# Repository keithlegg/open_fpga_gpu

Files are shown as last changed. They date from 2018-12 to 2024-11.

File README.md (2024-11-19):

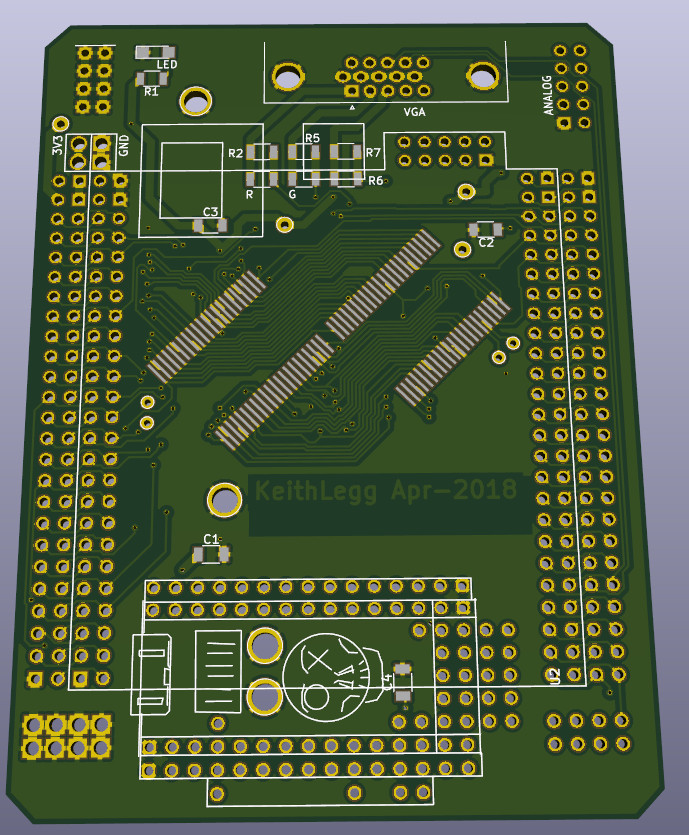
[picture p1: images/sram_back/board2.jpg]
 

# open_fpga_gpu

HERE THERE BE DRAGONS.

This is an experiment. This is probably never going to be much more than that. 

It currently works as an SRAM framebuffer, it can draw the contents of memory to VGA and only draws a single line on the screen.

There will be much done to it before it is even close to ready to be called a "GPU".

HARDWARE:

Features 2 IS62WV51216BLL SRAM chips.

Each SRAM chip has 512K x 16 CMOS low power static RAM

Both chips share the address and data bus with separate programable control lines.

Also has a slot for a 1bitsy ARM chip, not wired directly to the FPGA but there are headers if you want to.

Every mojo pin has been broken out so you can snoop with logic tools, or reconfigure how you want. 
This makes the board much larger, but keeps things easier for prototyping. 

The verilog is added to the mojo-base-project found here:

    https://github.com/embmicro/mojo-base-project

Just copy the files into the src folder, and add the link in ISE GUI before you build the project.

Bresenham code borrowed from here:

    https://github.com/kavinr/Bresenham-Line-Drawing-Algorithm

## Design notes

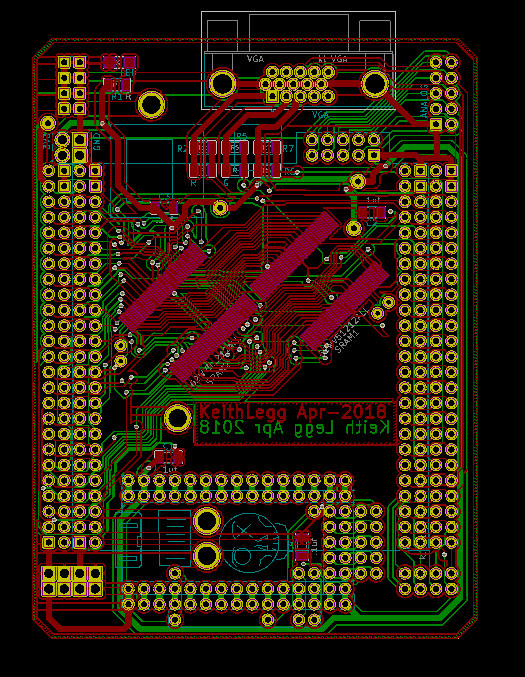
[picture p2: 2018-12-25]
images/sram_back/board1.jpg

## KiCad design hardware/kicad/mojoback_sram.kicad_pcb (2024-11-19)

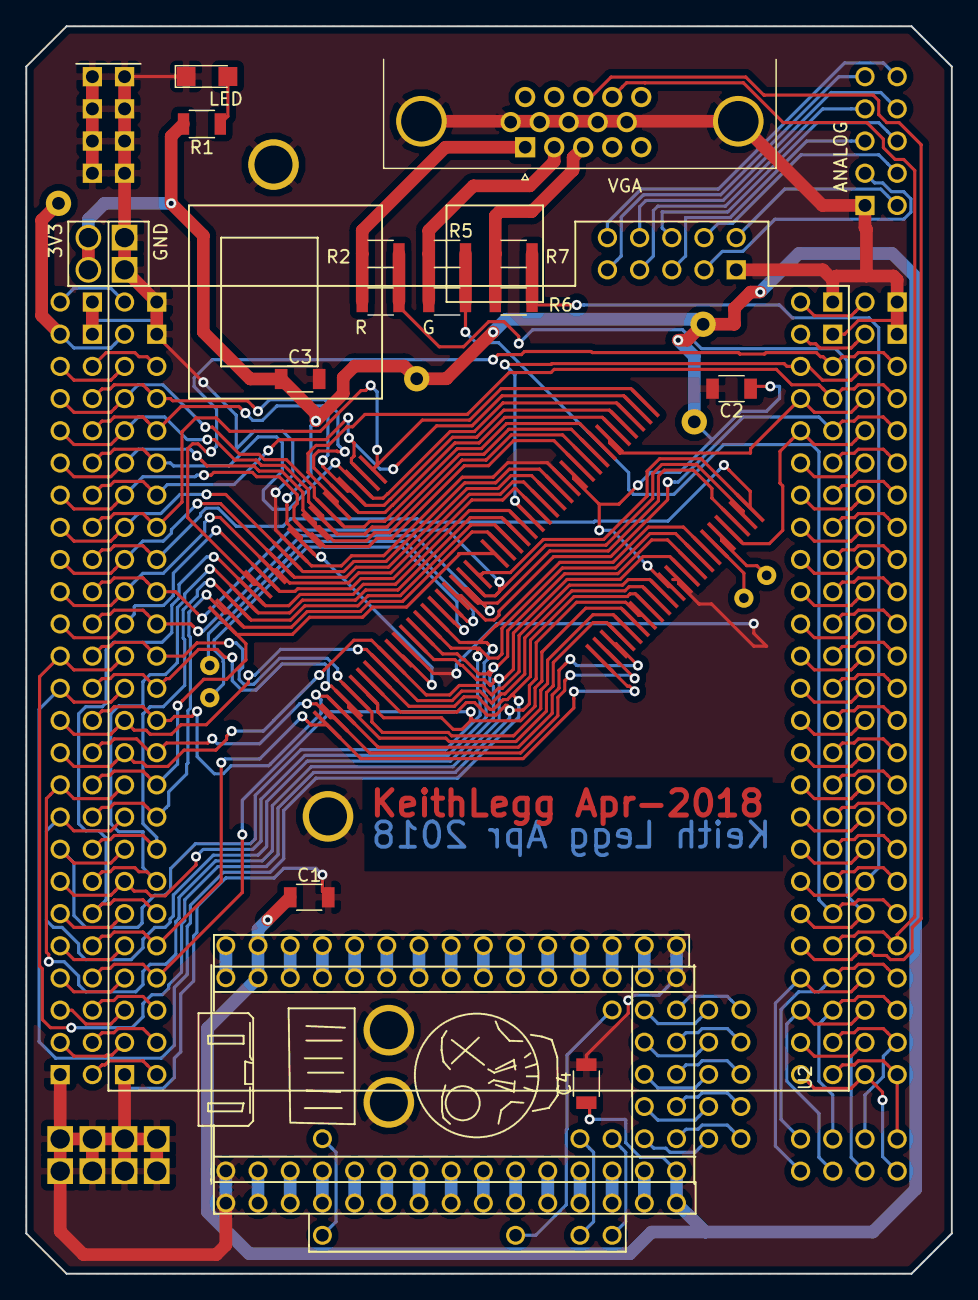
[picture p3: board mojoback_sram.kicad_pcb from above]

Board: 2 copper layers, 73.0 x 98.4 mm, 16 parts (0 on the bottom side), 44 nets.

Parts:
C1, C2, C3, C4: .1uf; C_1206
G: G; R_1206
LED: LED; LED_1206
R, R1: R; R_1206
R2, R5, R7: R_1206
R6: B; R_1206
SRAM1, SRAM2: 62WV51212ALL; KL_TSOP44_Pitch0.8mm
U2: kl_bitsy
VGA: kl_VGA; KL_VGA

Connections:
/3V3: C1.1, C2.1, C3.1, C4.1, R1.2, SRAM1.11, SRAM1.33, SRAM2.11, SRAM2.33, U2.18, U2.42
/A0: SRAM1.5, SRAM2.5
/A1: SRAM1.4, SRAM2.4
/A2: SRAM1.3, SRAM2.3
/A3: SRAM1.2, SRAM2.2
/A4: SRAM1.1, SRAM2.1
/A5: SRAM1.44, SRAM2.44
/A6: SRAM1.43, SRAM2.43
/A7: SRAM1.42, SRAM2.42
/A8: SRAM1.27, SRAM2.27
/A9: SRAM1.26, SRAM2.26
/A10: SRAM1.25, SRAM2.25
/A11: SRAM1.24, SRAM2.24
/A12: SRAM1.22, SRAM2.22
/A13: SRAM1.21, SRAM2.21
/A14: SRAM1.20, SRAM2.20
/A15: SRAM1.19, SRAM2.19
/A16: SRAM1.18, SRAM2.18
/A17: SRAM1.23, SRAM2.23
/A18: SRAM1.28, SRAM2.28
/IO_0: SRAM1.7, SRAM2.7
/IO_1: SRAM1.8, SRAM2.8
/IO_2: SRAM1.9, SRAM2.9
/IO_3: SRAM1.10, SRAM2.10
/IO_4: SRAM1.13, SRAM2.13
/IO_5: SRAM1.14, SRAM2.14
/IO_6: SRAM1.15, SRAM2.15
/IO_7: SRAM1.16, SRAM2.16
/IO_8: SRAM1.29, SRAM2.29
/IO_9: SRAM1.30, SRAM2.30
/IO_10: SRAM1.31, SRAM2.31
/IO_11: SRAM1.32, SRAM2.32
/IO_12: SRAM1.35, SRAM2.35
/IO_13: SRAM1.36, SRAM2.36
/IO_14: SRAM1.37, SRAM2.37
/IO_15: SRAM1.38, SRAM2.38
/b_video: R6.2, R7.2
/clr_b: R6.1, R7.1, VGA.3
/clr_g: G.1, R5.1, VGA.2
/clr_r: R.1, R2.1, VGA.1
/g_video: G.2, R5.2
/r_video: R.2, R2.2
GND: C1.2, C2.2, C3.2, C4.2, LED.1, SRAM1.12, SRAM1.34, SRAM2.12, SRAM2.34, U2.1, U2.29, VGA.0
unnamed: LED.2, R1.1

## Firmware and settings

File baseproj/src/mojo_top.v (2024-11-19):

module mojo_top(
    // 50MHz clock input
    input clk,
    // Input from reset button (active low)
    input rst_n,
    // cclk input from AVR, high when AVR is ready
    input cclk,
    // Outputs to the 8 onboard LEDs
    output[7:0]led,
    // AVR SPI connections
    output spi_miso,
    input spi_ss,
    input spi_mosi,
    input spi_sck,
    // AVR ADC channel select
    output [3:0] spi_channel,
    // Serial connections
    input avr_tx,      // AVR Tx => FPGA Rx
    output avr_rx,     // AVR Rx => FPGA Tx
    input avr_rx_busy, ////

    /********/
    //SPI1 - keith was here, went for beer 
    input klspi_cs,
    input klspi_clk, 
    input klspi_mosi, 
    output klspi_miso,
    /********/
    //SPI2 - echo SPI for logic analyzer snooping - all outputs  
    output klspi_cs_2,
    output klspi_clk_2,
    output klspi_miso2,
    output klspi_mosi2,

    /********/  
    //SRAM data and address buses 

    inout[15:0]sram_bidir, 
    output[18:0]sram_a,

    /********/ 
    //sram1 control bus 
    output sram1_we,//active low
    output sram1_cs,//active low
    output sram1_oe,//active low

    //sram2 control bus 
    output sram2_we,//active low
    output sram2_cs,//active low
    output sram2_oe,//active low

    /********/    
    //VGA output        
    output rpin,
    output gpin,
    output bpin,
    output vpin,
    output hpin

    );


/********************************/

wire inv_rst;         
assign inv_rst = ~rst_n;

/********************************/
//initialize values - "plugz"

// these signals should be high-z when not used
assign spi_miso = 1'bz;
assign avr_rx = 1'bz;
assign spi_channel = 4'bzzzz;


//echo SPI to second bus 
assign klspi_cs_2 = klspi_cs;
assign klspi_clk_2 = klspi_clk; 
assign klspi_mosi2 = klspi_mosi; 
assign klspi_miso = 1'b1;
assign klspi_miso2 = 1'b1;

/******************************************/
// SRAM interface  - chip1 is on right of board when VGA is top 
/******************************************/

wire we_wire1; // high on read, low on write 
wire oe_wire1; // low on read , high on write 

wire we_wire2; // high on read, low on write  
wire oe_wire2; // low on read , high on write 

// sram1 control buses 
assign sram1_we = 1'b1; //we_wire1; // high means READ data (active low) 
assign sram1_cs = 1'b1;             // low is selected      (active low) 
assign sram1_oe = 1'b1; //oe_wire1; // low on read          (active low)  

assign sram2_we = we_wire2;   // high means READ data (active low)
assign sram2_cs = ~rst_n;     // low is selected      (active low) 
assign sram2_oe = oe_wire2;   // low on read          (active low)

reg [7:0] led_intermed; //led output signal - 8bit

/********************************/
//CLOCK DIVIDER
wire blink;
reg [23:0] counter_d, counter_q;

assign blink = counter_q[23];

always @(counter_q) begin
    counter_d = counter_q + 1'b1;
end
always @(posedge clk) begin
    if (inv_rst) begin
        counter_q <= 24'b0;
        //cur_state=STATE_RESET; //only ONE block can set a value
    end else begin
        counter_q <= counter_d;
    end
end

/********************************/

reg dir_pin = 1'b1;

wire [15:0] data_intermed;

reg[18:0] addr_cntr1 = 19'd0;

reg[15:0] sram_data_in = 16'd0;


/********************************/
//bidirectional pin code - SRAM read/write 
/********************************/
reg  half_clk;

sram_io shramio(
    .clk(clk),
    //data to interact with sram chip 
    .wren(dir_pin),
    .d(sram_data_in),
    .q(data_intermed),
    .address(addr_cntr1),
    //physical wires to control sram chip 
    .WE(we_wire2),
    .OE(oe_wire2),
    .ADDR(sram_a), 
    .IO(sram_bidir) 
);

/***********************************************/
/***********************************************/
//VGA portion 

//cut clock in half to 25mhz

always @(posedge clk) 
begin
    half_clk <= ~half_clk;
end

/******************/

wire inDisplayArea;
wire [18:0] CounterX;
wire [18:0] CounterY;

wire [18:0] mem_ptr;

hvsync_generator syncgen(.clk(half_clk), 
                         .sram_addr(mem_ptr), 
                         .vga_h_sync(hpin), 
                         .vga_v_sync(vpin),
                         .inDisplayArea(inDisplayArea), 
                         .CounterX(CounterX), 
                         .CounterY(CounterY));

reg vga_R;
reg vga_G;
reg vga_B;


 

/***************************************/

//3 STATE - ERASE, DRAW, SHOW SRAM 

reg [18:0] high_addr  =  19'd216800; //19'd416800; //521*800
reg [18:0] high_addr2 =  19'd416800; //19'd416800; //521*800

//very basic state machine 
reg [3:0] run_state = 4'd0; //clear /write pattern/ run 

// reg [18:0] cntr_x = 19'h0;
// reg [18:0] cntr_y = 19'h0;
reg [7:0] linecount = 8'h0;

reg [19:0] krazycount = 20'b0;



always @(posedge clk) begin

        if (addr_cntr1 < high_addr2) begin
            sram_data_in = 0;
            addr_cntr1 <= addr_cntr1 + 1;
        end
        // overflow condition - reset count and start over      
        else begin
            addr_cntr1 <= 19'b0;
            //go to next state
            run_state <= 4'd1;  
        end
        
end

/*
always @(posedge clk) begin
    //clear sram 
    if (run_state == 4'd0) begin
        if (addr_cntr1 < high_addr2) begin
            sram_data_in = 0;
            addr_cntr1 <= addr_cntr1 + 1;
        end
        // overflow condition - reset count and start over      
        else begin
            addr_cntr1 <= 19'b0;
            //go to next state
            run_state <= 4'd1;  
        end
    end

    //write to sram 
    if (run_state == 4'd1) begin
        // SRAM address to stop writing  
        if (addr_cntr1 < high_addr) begin
            // attempt to make a visual pattern in sram
            addr_cntr1 <= addr_cntr1 + 1;

            if (addr_cntr1 > 19'd9600 && addr_cntr1 < 19'd10200) begin        // Y 12
                sram_data_in = 16'd350;
            end
            else if (addr_cntr1 > 19'd80020 && addr_cntr1 < 19'd80300) begin // Y 100
                sram_data_in = 16'd150;
            end            
            else begin
                sram_data_in = 16'd0;
            end

        end
        // overflow condition - reset count and start over 
        else begin
            addr_cntr1 <= 19'b0;
            run_state <= 4'd2; //go to next state 
                
        end   
    end

    if (run_state == 4'd2)begin
        if (dir_pin == 1'b1) begin 
            dir_pin <= 1'b0; //set SRAM to read instead of write  
        end
        addr_cntr1 <= mem_ptr;
    end
*/





/***************************************/

/*
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
